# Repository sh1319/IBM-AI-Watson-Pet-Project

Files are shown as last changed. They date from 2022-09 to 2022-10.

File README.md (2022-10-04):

# ICL-IBM-AI-Watson-Pet
 The AI Watson pet is an AI ornament with the characteristics of a pet, designed to target the impact of social isolation for the elderly. The pet will interact with its owner, and perform various actions depending on what the owner wants it to do. This will give the owners the mental health benefits of having a pet, without the responsibility and expenses of actually caring for one. The aim of the project is to create a smart pet with AI technology to interact with its owner successfully.

## Video Link:
https://drive.google.com/drive/folders/1X8JHZ7TH7rixMnBctJGE3ZhGvCP7YAib?usp=sharing

## Audio MP3 Link:
https://drive.google.com/drive/folders/1X8JHZ7TH7rixMnBctJGE3ZhGvCP7YAib?usp=sharing

## Trello Project Board Link:
https://trello.com/invite/b/4JAl3sjE/0ff0876919062a6ea0753fef662f85e3/ai-watson-pet

## Hardware Part Info

This repo contains all the code required to run your own Watson AI Pet!

Folders 'CAD/Model1' and 'CAD/Model2' contain the CAD files required to 3D print your own pet!
The "App" folder contains the code for the mobile app as described in the software part.

The external components should then be wired up to the correct ports as seen in the circuit diagram in the main report.
Required Components:
1. 4 x Adafruit Bicolor LED Square Pixel Matrix with I2C Backpack
2. 3 x Adafruit Momentary Capactive Touch Sensor
3. 2 x Servo Motors
4. 1 x Adafruit Stereo 2.8W Class D Audio Amplifier
5. 1 x Adafruit I2S MEMS Microphone Breakout Board

Correct wiring, at least for I2S devices, can be checked using the command:
> sudo i2cdetect -y 1

This will reveal the I2S devices that the RPi can see and communicate with. If wired correctly, there should be devices at 0x70, 0x71, 0x72, 0x73 and 0x58. (You will need to solder the pins on the back of the LED matricies to change their address, or else they will all try to be address 0x70). If the program takes a while to load or doesn't show all of these devices, check your SDA and SCL connections.

A Raspberry Pi Model 3B was used for this project with the following specs:
Required Specs:
1. Quad Core 1.2GHz Broadcom BCM2837 64bit CPU
2. 1GB RAM
3. BCM43438 wireless LAN and Bluetooth Low Energy (BLE) on board
4. 40-pin extended GPIO

Useful for debugging:
1. Full size HDMI
2. 4 USB 2 ports

To run the pet, be sure to install the required packages using:

> sudo pip3 install <package_name>

Required packages include those in routines/general/requirements.txt and the following:
1. adafruit-circuitpython-ht16k33
2. python3-pil
3. adafruit_tpa2016
4. gpiozero
5. digitalio

Then, you should be able to run the main program (ideally at startup) with:

> sudo python3 main.py

The program requires sudo access as the BlueTooth Wifi module requires this to change the wifi settings and reboot the system. (This is why the packages must also be installed with sudo).

### Sub-Modules
Pet sub-modules can be found in 'routines/' as well as 'handlers' for each sub-module that are responsible for the functionality and proper-operation of that sub-module.

- routines/audioIO controls the speaker and microphone with functions to handle both pre-recorded and dynamic playback (using Text-To-Speech), as well as getting a user response (using speech to text).

- routines/displays controls all of the LEDs using a bunch of predefined scripts and 8x8 images to fill them up. It supports both static images and animations (for things such as speaking or thinking)

- routines/general contains all the code from the software side of the project and is the real brains behind the assistant.

- routines/motors contains the code to drive the motors. This should happen when the pet is touched or bored and seeking attention.

- routines/pet contains the Pet object that contains and controls all other classes listed here. It has control of everything (can start or terminate any other process) and it used to synchronise everything. As such, it has defined some higher level functions such as speak() and listen() which controls the speakers and starts the thinking animation on the displays for example. It also handles the logic of what to do when it is touch and when to launch the assistant.

- routines/sensors contains the code to read from the GPIO touch tensors on the top and the side and contains a function which returns which side has been pressed.

When the main program is run as above, the routines/pet class is instantiated and from there everything else is created, checked and controlled. The main process to run this class is then blocked in a while True loop so that the program nevver terminates and the assistant will always be available once it has finished a request.

## Software Part Info
The software sessions codes are mostly within routines/general folder. There is an extra Readme file in that folder explaining those functions.
### Setting up 
The following set up are required for Watson AI Pet project. These are required for using the APIs. 

#### Spotify
1. Go to https://developer.spotify.com/dashboard/login and login to the developer dashboard. (This requries a spotify account)
2. Create an APP or use a exising one if you wish. 
3. Go to 'Edit Settings' and set the redirect url (normally set: https://localhost/)
4. Edit 'USER AND ACCESS' to add your spotify account to it as well as other people's account
5. Copy the client id and client secret and paste them into the routines/general/credentials.json file 

#### Youtube and Google Calendar
1. Follow instructions on https://developers.google.com/workspace/guides/create-project and create a google cloud project
2. On the left top corner select Navigation Menu and navigate to 'API and Services' followed by 'Library'
3. Search for youtube and enable 'Youtube Data API v3'. Search for calendar and enable 'Google Calendar API'  
4. Click credentials and select API key and copy that to routines/general/credentials.json in google_developerkey
5. Click credentials and select OAuth Client ID and select TV and limited Input Device and click create
6. Select the TV and limited Input Device and download credentials
7. Copy the cliend id and cliend secret in the downloaded json file and past them into routines/general/credentials.json

#### Mongodb Atlas
1. Go to https://account.mongodb.com/account/login and create a Mongodb Atlas account 
2. Create a new Cluster
3. Click Connect and select Connect with your application
4. Set the driver to Python and version to 3.4 or later.
5. Follow the instructions on page and copy the url below into routines/general/credentials.json

#### IBM
1. You need to have an IBM cloud account for this proejct.(For our project, Trail account is used.)
2. Go to IBM cloud dashboard and search for 'assistnat', 'natural language understanding','speech to text' and 'text to speech' services.
3. Create all services and set with same location and select the plan you desire, the lite plan should work.

##### For IBM assistant 
1. Open the assistant service, on the top right,click the user haed and switch to classic experience.
2. Copy the API key and URL below to routines/general/credentials.json
3. Click 'Launch' and create assistant
4. Click 'Add dialog skill' and choose 'Upload Skill'
5. Upload the file assistant.json
6. Go back to the page with Assistants, select the 3 dots on the right of the assistant just created and go to settings
7. Copy the assistant_id to routines/general/credentials.json

##### For IBM natural language understanding, speech to text and text to speech services
1. Open the natural language understanding service, copy the API and URL below to corresponding positions in routines/general/credentials.json

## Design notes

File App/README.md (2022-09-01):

# Android App
## Preview
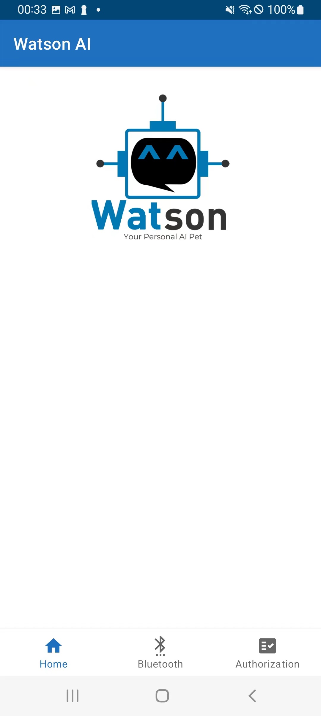
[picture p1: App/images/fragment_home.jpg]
[](image.jpg)
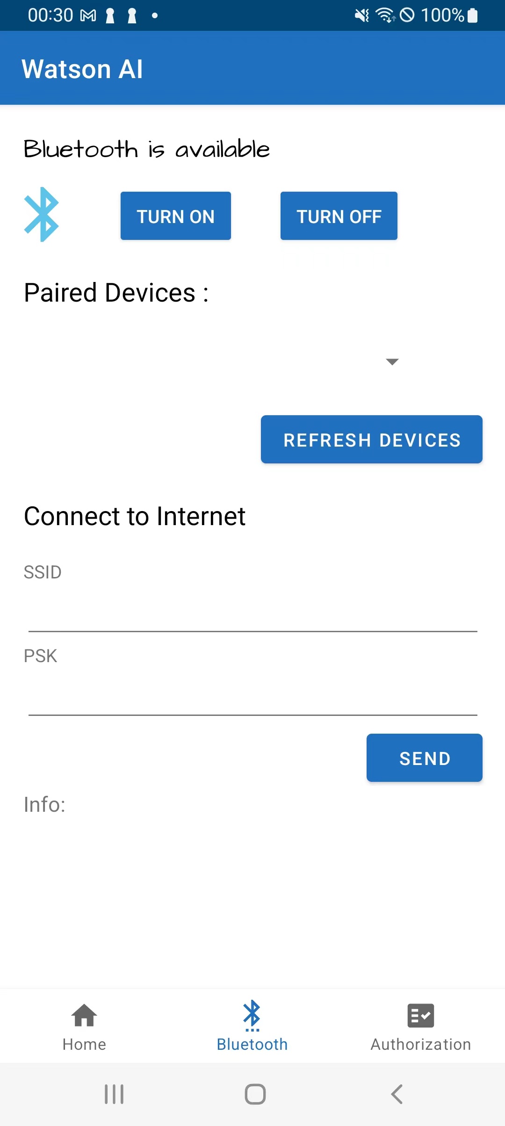
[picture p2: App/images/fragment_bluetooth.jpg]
[](image.jpg)
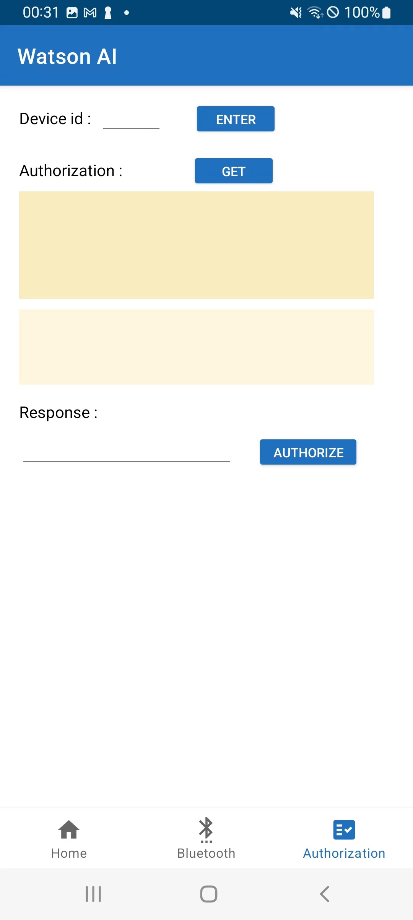
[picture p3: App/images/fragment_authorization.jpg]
[](image.jpg)

## Specification
This folder contains all the file need to build the android app for the AI Watson Pet.  
The main files are included in folder [main](android_app/app/src/main/).

### Manifest File
[AndroidManifest.xml](android_app/app/src/main/AndroidManifest.xml) : The manifest file describes essential information about the app to the Android build tools and the Android operating system, which includes the permissions the application requires access to and also declares the android api that the application is going to use.  

### Layout Related File
[main/res](android_app/app/src/main/res/) : This folder contains layout related files, including images used, colors, fonts and etc.
- [layout](android_app/app/src/main/res/layout) : This folder contains all the files required to design the overall layout of the application.
  - [activity_main.xml](android_app/app/src/main/res/layout/activity_main.xml) : This file controls the layout of botton navigation and fragment.
  - [fragment_home.xml](android_app/app/src/main/res/layout/fragment_home.xml), [fragment_bluetooth.xml](android_app/app/src/main/res/layout/fragment_buetooth.xml), and [fragment_authorization.xml](android_app/app/src/main/res/layout/fragment_authorization.xml) : These three files are responsible for designing the layout of each fragment.
  - [bluetooth_devices.xml](android_app/app/src/main/res/layout/bluetooth_devices.xml) and [bluetooth_devices_v1.xml](android_app/app/src/main/res/layout/bluetooth_devices_v1.xml) : These two are helper functions for designing the layout of the spinner.
- [navigation/main_nav.xml](android_app/app/src/main/res/navigation/main_nav.xml) : This is the xml file used to control the three navigation fragments.

### Java Classes
[navigation](android_app/app/src/main/java/com/example/navigation/) : This folder contains all the java classes created to provide various functionalities.
- [MainActivity.java](android_app/app/src/main/java/com/example/navigation/MainActivity.java) : This java class sets up the overall navigation view and also set the title of the actionbar.
- [HomeFragment.java](android_app/app/src/main/java/com/example/navigation/HomeFragment.java) : This java class implements functions in the first fragment. The home fragment shows some general information about the Watson pet and the app. 
- [BluetoothFragment.java](android_app/app/src/main/java/com/example/navigation/BluetoothFragment.java) : This java class implements functions in the second fragment. This fragment is mainly used for turning on the bluetooth of the phone, finding the paired Watson Pet, and sending the local wifi name and password to Watson via bluetooth. This allows the pet to connect to the local wifi and provide services.
- [AuthorizationFragment.java](android_app/app/src/main/java/com/example/navigation/AuthorizationFragment.java): This java class implements functions in the third fragment. It is mainly responsible for doing authorization for Google, Spotify and Twitter. Mqtt is used to transfer message among the mqtt broker, the Watson ai pet and the android app.   
- [BluetoothDeviceAdapter.java](android_app/app/src/main/java/com/example/navigation/BluetoothDeviceAdapter.java): This java class helps to set the content of the spinner as well as the drop down view.

## How to run
### Method 1
If you have Android Studio downloaded, just import the whole [app](android_app/app/) folder into the Android Studio, connect the android phone to computer and run it.

### Method 2
Download the apk and metadata file together under the folder apk_unsigned to your android phone. Remember to changes settings to allow install of unknown apps.

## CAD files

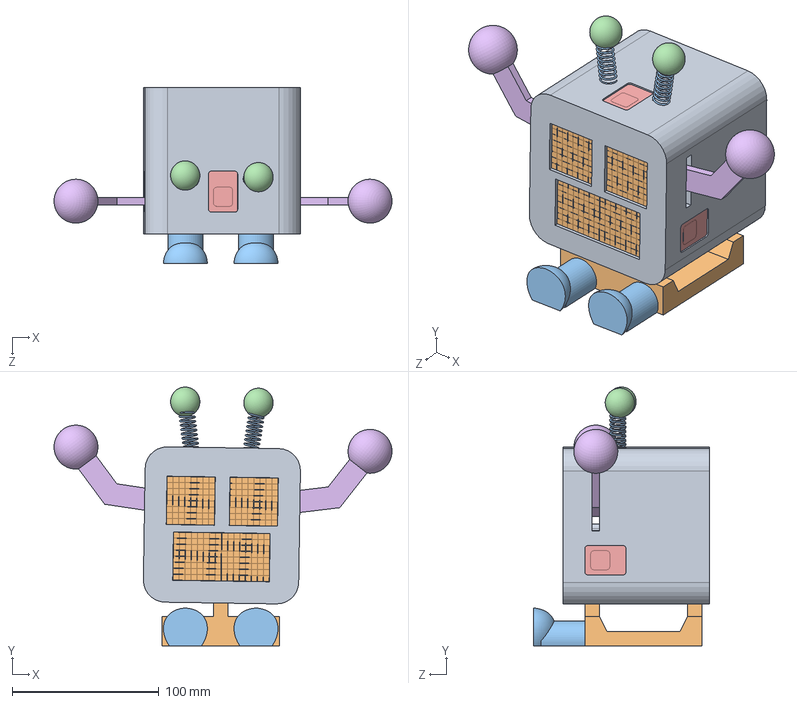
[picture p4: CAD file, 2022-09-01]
CAD/Model1/Assembly.SLDASM
230.6 x 176.7 x 120.0 mm
head outer
LED matrix x 4
head spring x 2
spring ball x 2
touch sensor x 3
arm x 2
temp motor x 2
speaker
bobble support x 2
leg
optional foot x 2

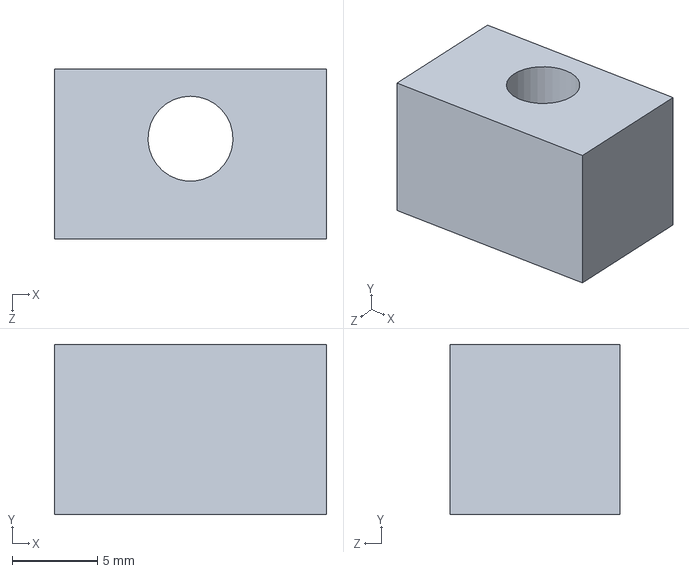
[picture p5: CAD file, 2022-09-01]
CAD/Model1/temp motor.SLDPRT
16.0 x 10.0 x 10.0 mm

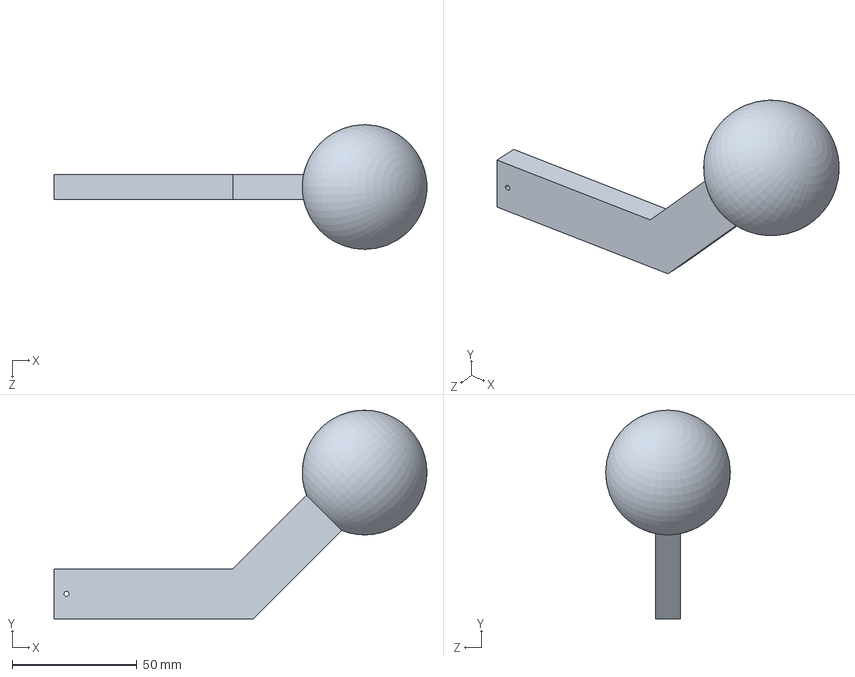
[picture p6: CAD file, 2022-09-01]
CAD/Model2/arm.SLDPRT
149.5 x 83.6 x 50.0 mm

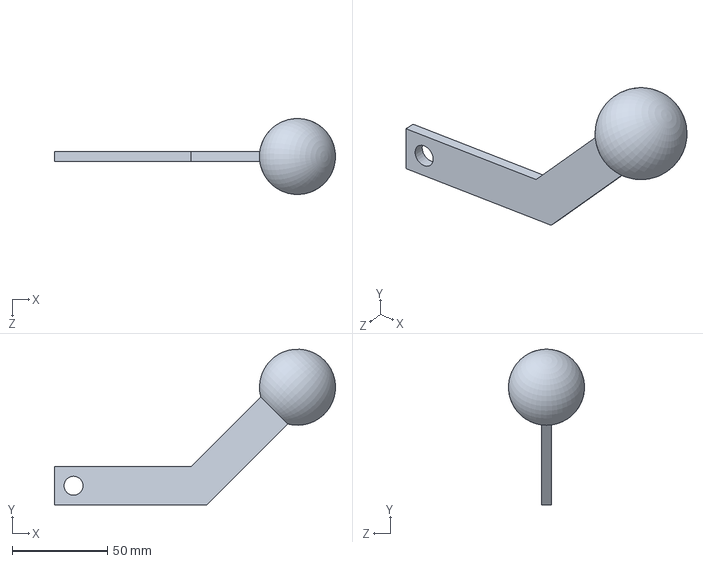
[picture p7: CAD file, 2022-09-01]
CAD/Model1/arm.SLDPRT
147.6 x 81.7 x 40.0 mm

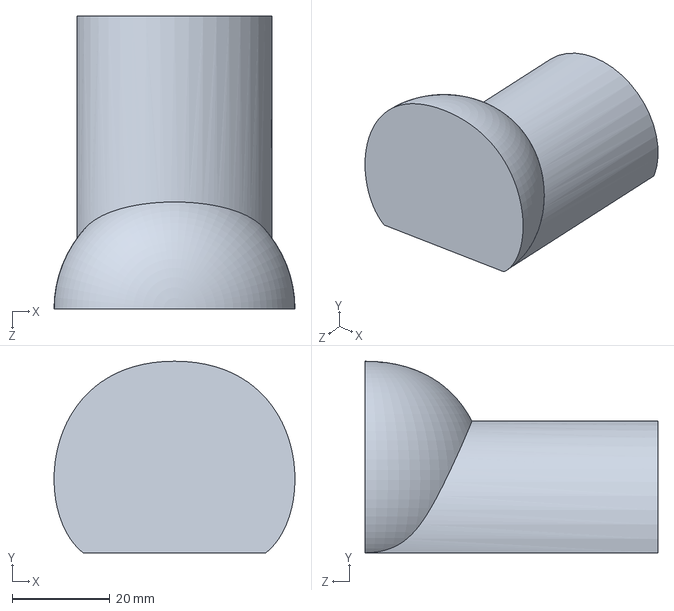
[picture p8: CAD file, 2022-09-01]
CAD/Model2/optional foot.SLDPRT
49.4 x 39.3 x 60.0 mm

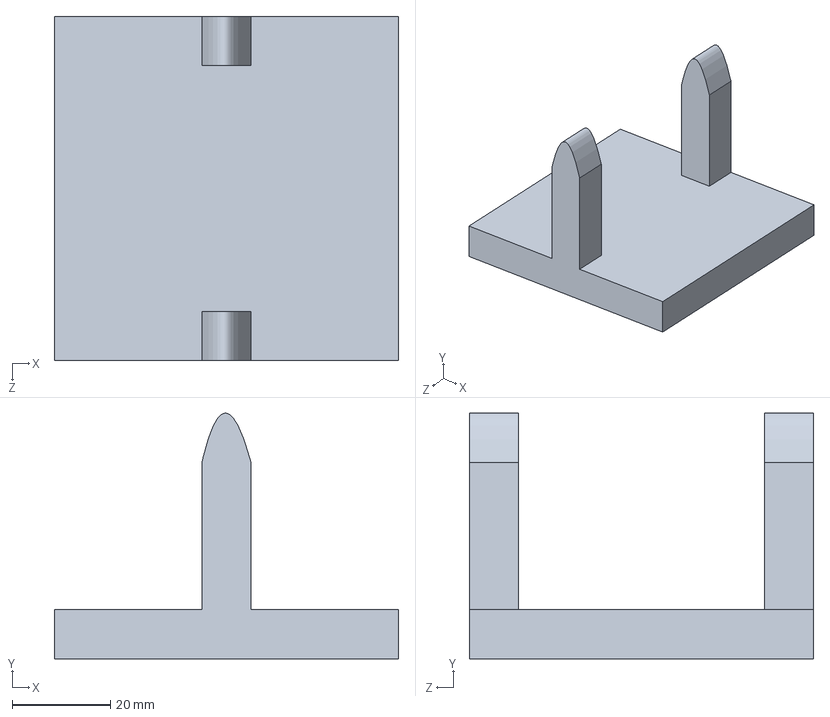
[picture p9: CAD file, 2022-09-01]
CAD/Model1/leg.SLDPRT
70.0 x 50.0 x 70.0 mm

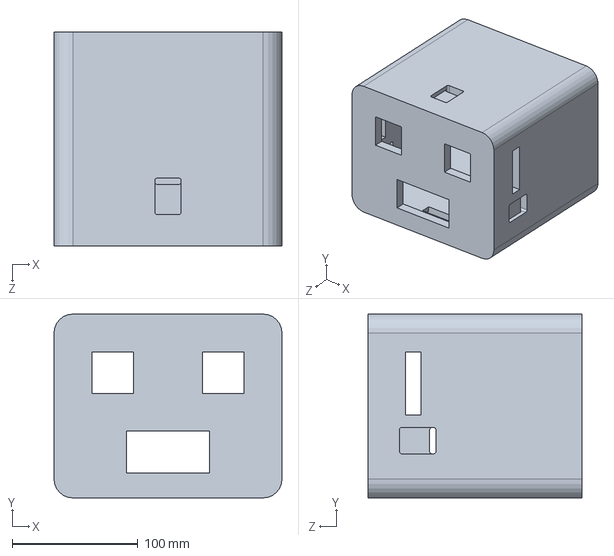
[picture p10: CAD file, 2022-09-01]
CAD/Model2/head outer.SLDPRT
181.0 x 146.0 x 170.0 mm

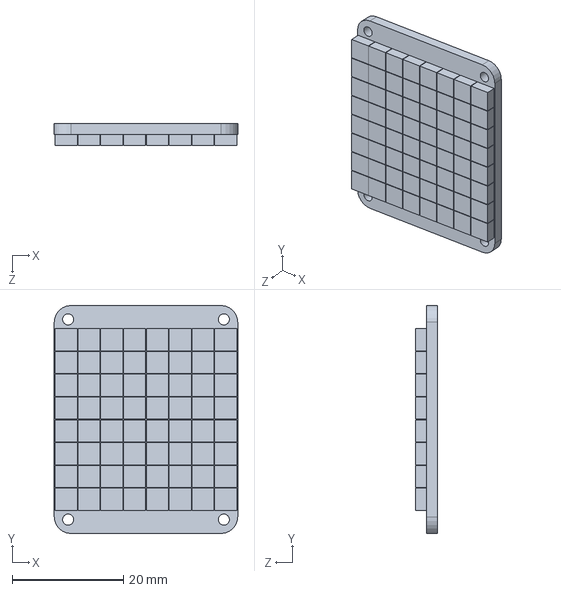
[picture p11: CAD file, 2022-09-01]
CAD/Model1/LED matrix.SLDPRT
33.0 x 41.0 x 4.00 mm

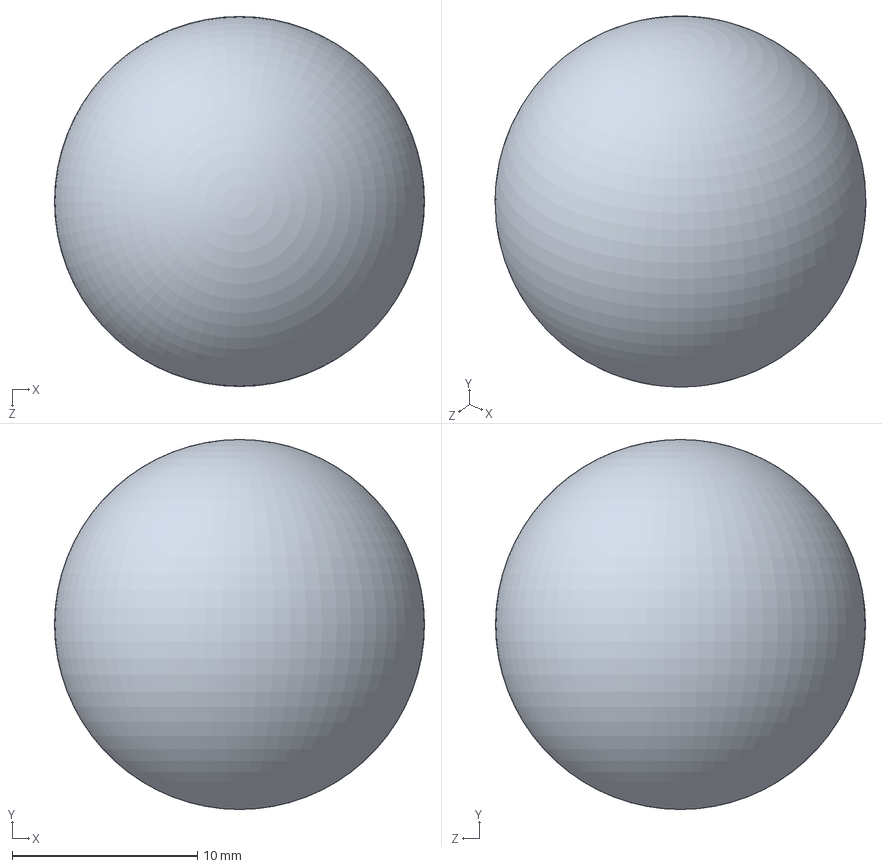
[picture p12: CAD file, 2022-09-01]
CAD/Model1/spring ball.SLDPRT
20.0 x 20.0 x 20.0 mm

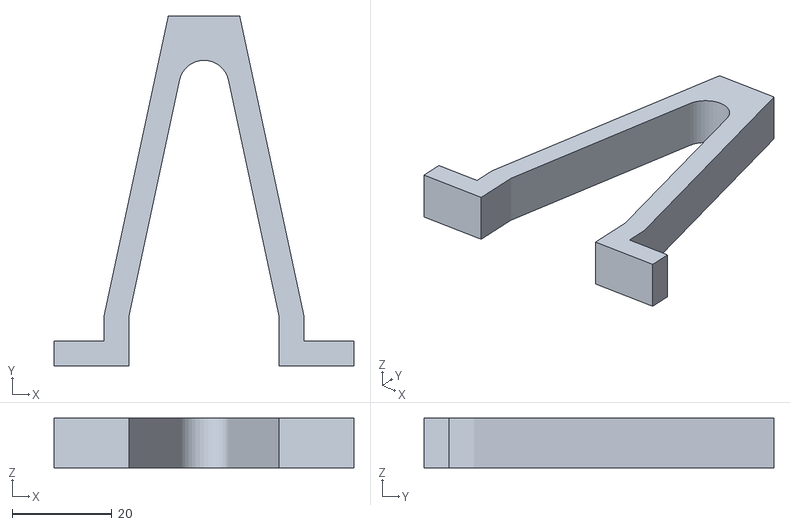
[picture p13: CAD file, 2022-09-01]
CAD/Model2/bobble support2.STL
60.0 x 70.0 x 10.0

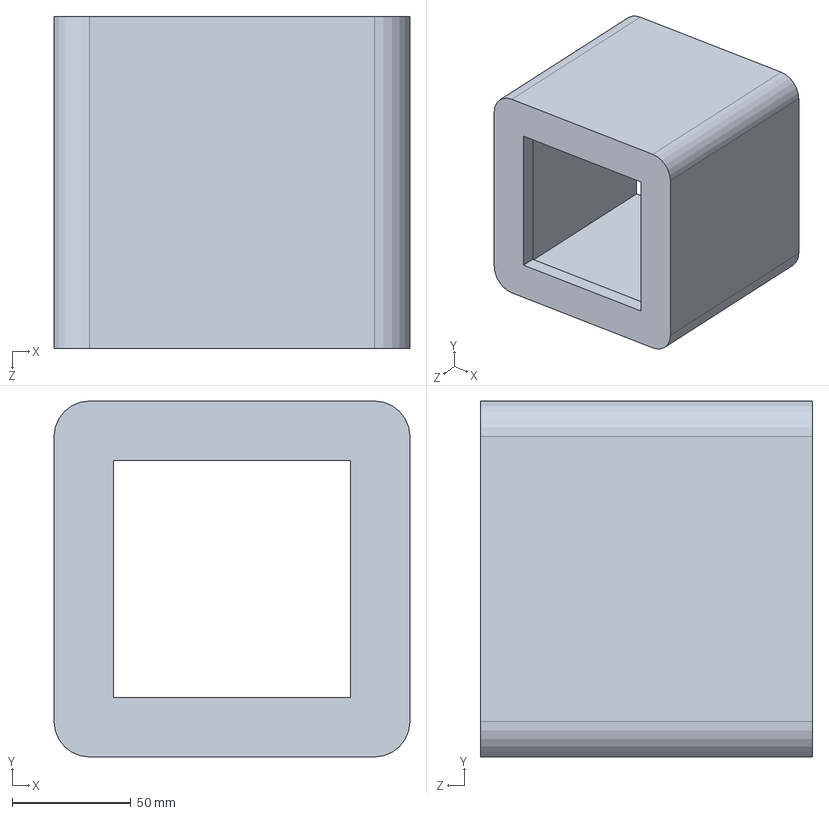
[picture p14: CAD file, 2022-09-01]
CAD/Model1/head outer.SLDPRT
150.0 x 150.0 x 140.0 mm

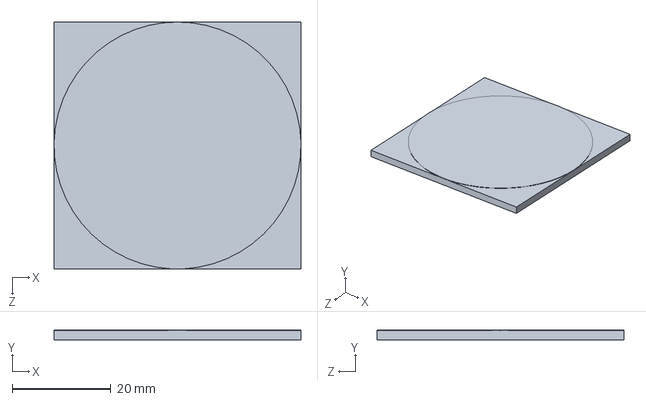
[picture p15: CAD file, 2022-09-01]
CAD/Model1/speaker.SLDPRT
50.0 x 2.10 x 50.0 mm

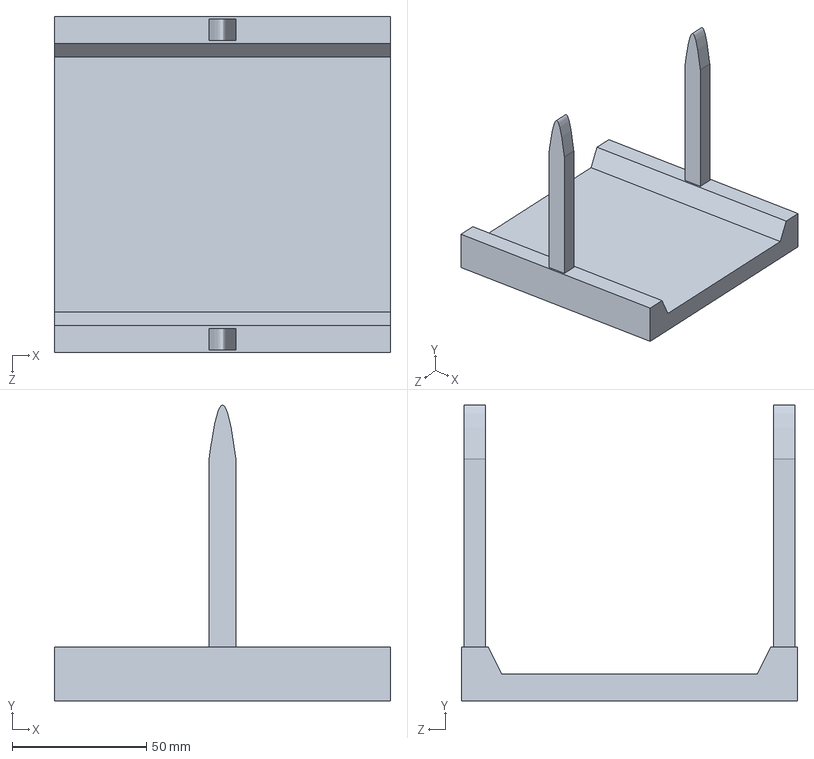
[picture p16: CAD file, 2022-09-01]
CAD/Model2/leg.SLDPRT
125.0 x 110.0 x 125.0 mm

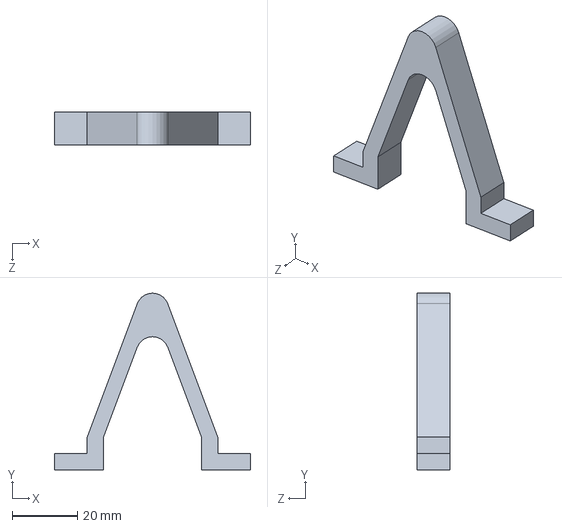
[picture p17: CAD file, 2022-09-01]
CAD/Model1/bobble support.SLDPRT
60.0 x 54.1 x 10.0 mm

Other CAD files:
CAD/Model2/arm right.SLDPRT
CAD/Model2/foot1.STL
CAD/Model2/foot2.STL
CAD/Model1/touch sensor.SLDPRT
CAD/Model1/head spring.SLDPRT
CAD/Model1/optional foot.SLDPRT
CAD/Model2/arm left.STL
CAD/Model2/arm right.STL
CAD/Model2/bobble support.SLDPRT
CAD/Model2/bobble support1.STL
CAD/Model2/head outer.STL
CAD/Model2/leg.STL

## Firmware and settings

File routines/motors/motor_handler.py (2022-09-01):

#https://www.digikey.co.uk/en/maker/blogs/2021/how-to-control-servo-motors-with-a-raspberry-pi
import time
import multiprocessing

from gpiozero import Servo

from routines.motors.animate.play import animate as animate_play

class Motors:
    def __init__(self):
        self.process = None
        self.left_arm = Servo(10)
        self.right_arm = Servo(24)

        
    def terminate_if_moving(self):
        if (self.process is not None):
            self.process.terminate()
            self.process = None
    
    def play(self):
        self.terminate_if_moving()
        self.process = multiprocessing.Process(target=animate_play, args=(self.left_arm, self.right_arm))
        self.process.start()

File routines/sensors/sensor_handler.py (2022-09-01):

import time
import board
from digitalio import DigitalInOut, Direction

class Sensors:
    def __init__(self):
        top_pin = board.D4
        left_pin = board.D22
        right_pin = board.D27

        self.top_pad = DigitalInOut(top_pin)
        self.left_pad = DigitalInOut(left_pin)
        self.right_pad = DigitalInOut(right_pin)

        self.top_pad.direction = Direction.INPUT
        self.left_pad.direction = Direction.INPUT
        self.right_pad.direction = Direction.INPUT

        # self.process = None
    
    # def terminate_if_scanning(self):
    #     if (self.process is not None):
    #         self.process.terminate()
    #         self.process = None
    
    def check_inputs(self):
        if self.top_pad.value:
            return (True, "top")
        
        if self.left_pad.value:
            return (True, "left")
        
        if self.right_pad.value:
            return (True, "right")
        
        return False
